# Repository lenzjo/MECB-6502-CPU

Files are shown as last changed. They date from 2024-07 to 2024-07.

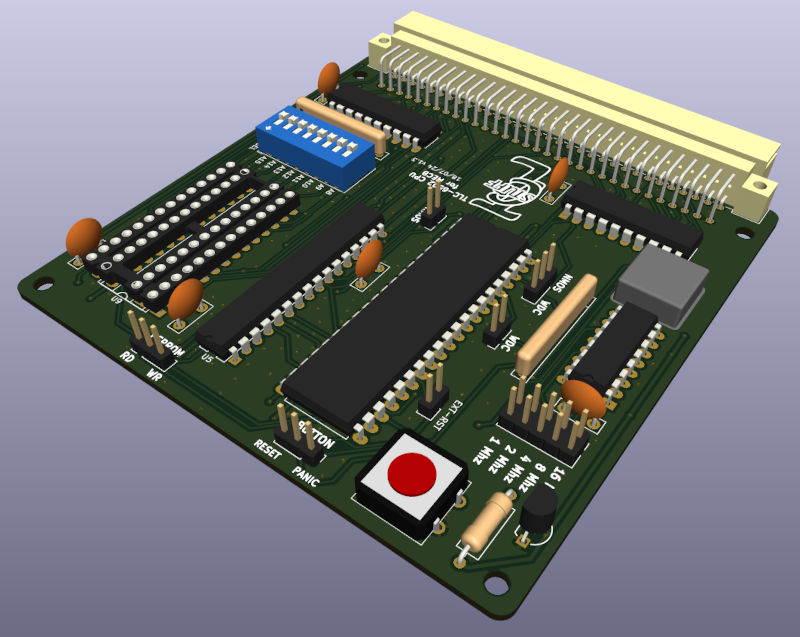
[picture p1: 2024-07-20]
TLC_6502_CPU.jpg

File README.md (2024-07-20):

# TLC-6502-CPU for MECB

This is the latest version of my 6502 pcb with several useful additions.

There are 3 sets of pin headers marked with **NMOS** and/or **WDC**. **WDC** refers to Western Digitals 65C02, If you're using that then jumper the pins marked **WDC**, otherwise jumper the **NMOS** marked pins.

This pcb uses a 16Mhz oscillator that is divided down to 1, 2, 4 and 8 Mhz. Jumper the relevant pair of pins for the clock speed you want.

The button's usage is jumper selectable. The **RESET** pin is connected to the reset line and the **PANIC** pin is connected to the **NMI** line. **PANIC** is only useful if your backplane has **Reset** button on it already, like mine. I am currently writing the needed firmware addition to TLCmon. If you are not using TLCmon then you will have to supply the necessary firmware.

The last set of pins (**EEPROM**) allow you to select if the eeprom is in either read or write mode. Under normal usage the **RD** pin should be jumpered.

You may have noticed the socket with double row pins. I have made a 28pin zif socket adapter that has pins spaced at 7.62mm. So on the pcb you use a cheap socket for the inner row of pins. When, if ever ;) , you finish developing your firmware you can solder in two rows of turned pins on the outer rows. I have included the gerbers for the adapter in the **gerbers** directory.

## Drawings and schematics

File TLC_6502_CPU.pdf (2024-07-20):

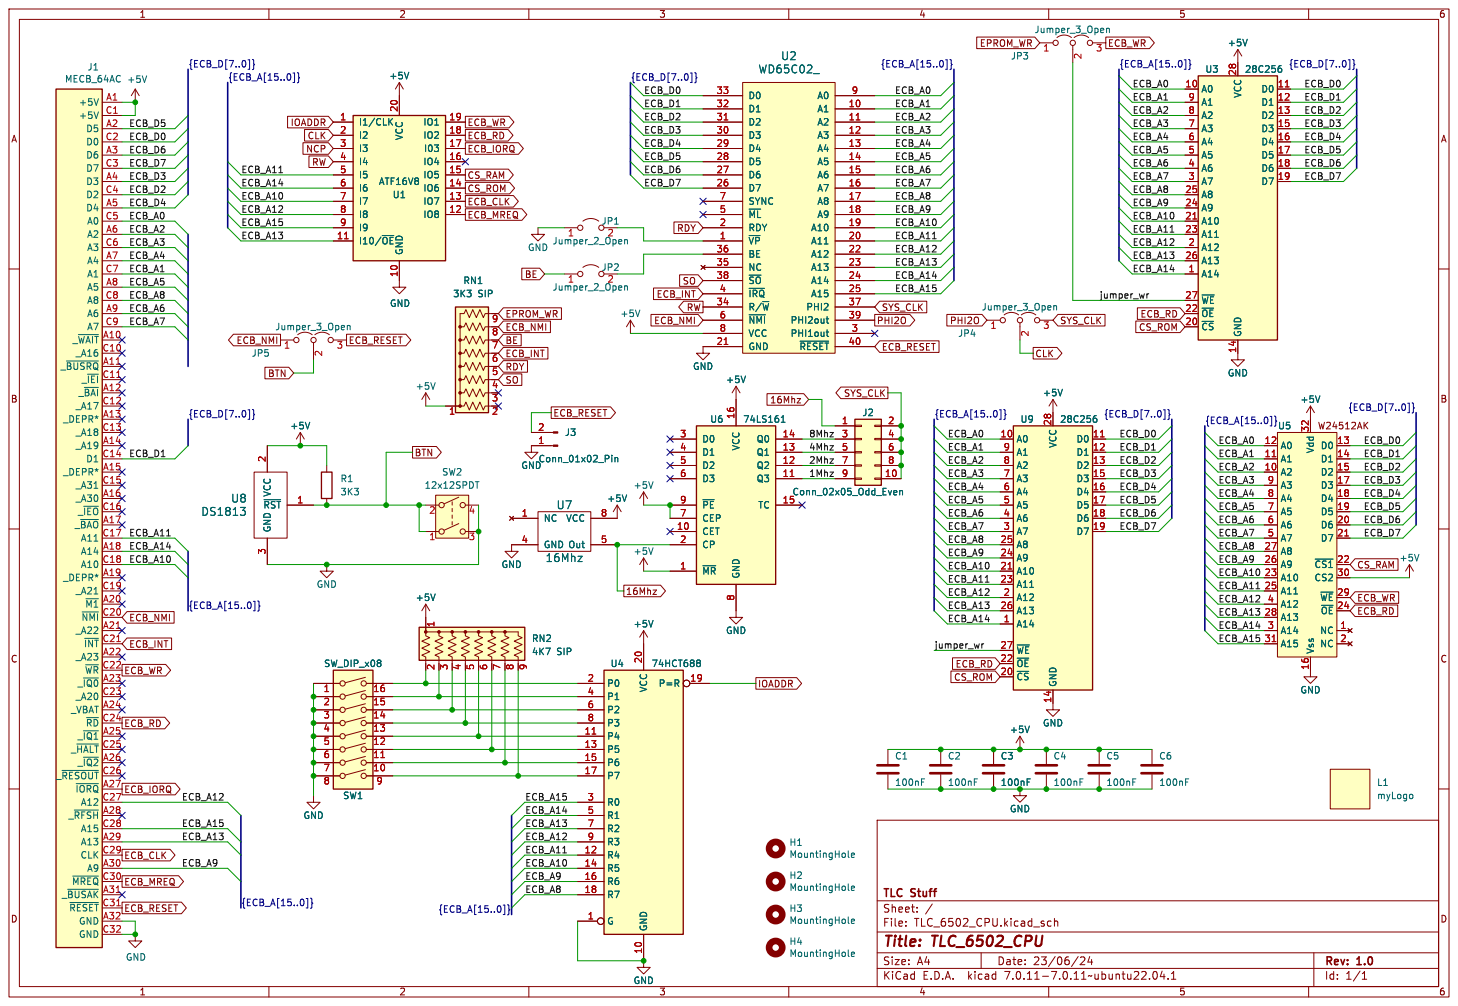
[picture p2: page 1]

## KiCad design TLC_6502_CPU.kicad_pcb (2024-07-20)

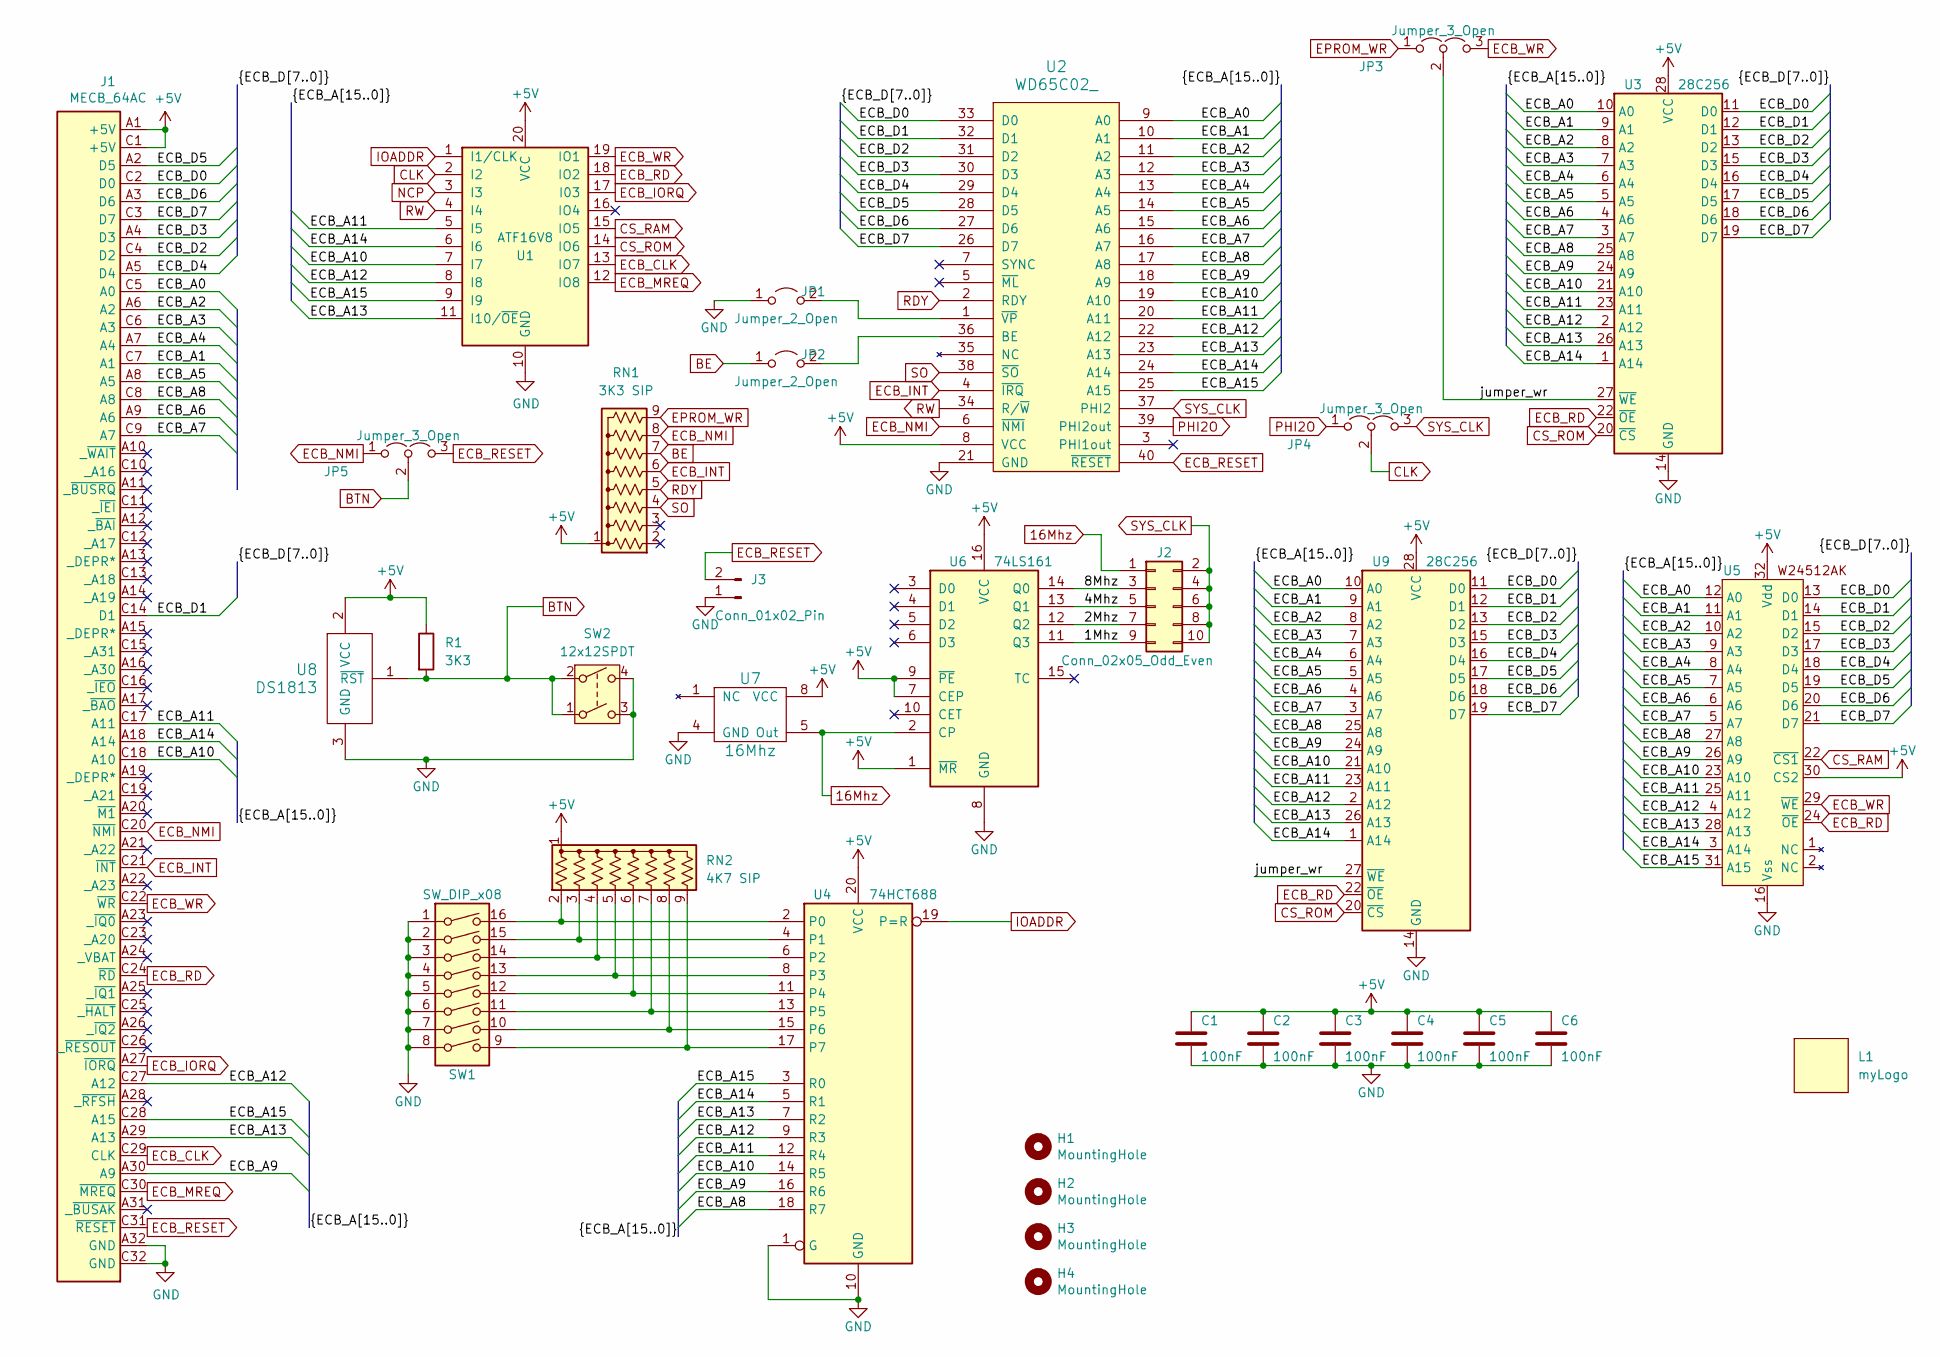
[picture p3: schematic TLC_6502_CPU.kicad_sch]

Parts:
C1, C2, C3, C4, C5, C6: 100nF; C_Disc_D7.5mm_W2.5mm_P5.00mm
H1, H2, H3, H4: MountingHole; MountingHole_3.2mm_M3
J1: MECB_64AC; DIN41612_C_2x32_C64AC_Male_Horizontal_THT
J2: Conn_02x05_Odd_Even; PinHeader_2x05_P2.54mm_Vertical
J3: Conn_01x02_Pin; PinHeader_1x02_P2.54mm_Vertical
JP1, JP2: Jumper_2_Open; PinHeader_1x02_P2.54mm_Vertical
JP3, JP4, JP5: Jumper_3_Open; PinHeader_1x03_P2.54mm_Vertical
L1: myLogo; LOGO_sm
R1: 3K3; R_Axial_DIN0309_L9.0mm_D3.2mm_P12.70mm_Horizontal
RN1: 3K3 SIP; R_Array_SIP9
RN2: 4K7 SIP; R_Array_SIP9
SW1: SW_DIP_x08; SW_DIP_SPSTx08_Slide_9.78x22.5mm_W7.62mm_P2.54mm
SW2: 12x12SPDT; 12x12-Tactile-Switch
U1: ATF16V8; DIP-20_W7.62mm_LongPads
U2: WD65C02_; DIP-40_W15.24mm_LongPads
U3: 28C256; DIP-28_W15.24mm_LongPads
U4: 74HCT688; DIP-20_W7.62mm_LongPads
U5: DIP-32_W7.62mm
U6: 74LS161; DIP-16_W7.62mm_LongPads
U7: 16Mhz; 4pinOsc
U8: DS1813; 21-0248A_MXM
U9: 28C256; DIP-28_W7.62mm_Socket_LongPads

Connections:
16Mhz: J2.1, U6.2 (CP), U7.5 (Out)
+5V: C1.1, C2.1, C3.1, C4.1, C5.1, C6.1, J1.A1 (+5V), J1.C1 (+5V), R1.1, RN1.1 (common), RN2.1 (common), U1.20 (VCC), U2.8 (VCC), U3.28 (VCC), U4.20 (VCC), U5.30 (CS2), U5.32 (Vdd), U6.1 (~MR), U6.7 (CEP), U6.9 (~PE), U6.16 (VCC), U7.8 (VCC), U8.2 (VCC), U9.28 (VCC)
/1Mhz: J2.9, U6.11 (Q3)
/2Mhz: J2.7, U6.12 (Q2)
/4Mhz: J2.5, U6.13 (Q1)
/8Mhz: J2.3, U6.14 (Q0)
/ECB_A0: J1.C5 (A0), U2.9 (A0), U3.10 (A0), U5.12 (A0), U9.10 (A0)
/ECB_A1: J1.C7 (A1), U2.10 (A1), U3.9 (A1), U5.11 (A1), U9.9 (A1)
/ECB_A2: J1.A6 (A2), U2.11 (A2), U3.8 (A2), U5.10 (A2), U9.8 (A2)
/ECB_A3: J1.C6 (A3), U2.12 (A3), U3.7 (A3), U5.9 (A3), U9.7 (A3)
/ECB_A4: J1.A7 (A4), U2.13 (A4), U3.6 (A4), U5.8 (A4), U9.6 (A4)
/ECB_A5: J1.A8 (A5), U2.14 (A5), U3.5 (A5), U5.7 (A5), U9.5 (A5)
/ECB_A6: J1.A9 (A6), U2.15 (A6), U3.4 (A6), U5.6 (A6), U9.4 (A6)
/ECB_A7: J1.C9 (A7), U2.16 (A7), U3.3 (A7), U5.5 (A7), U9.3 (A7)
/ECB_A8: J1.C8 (A8), U2.17 (A8), U3.25 (A8), U4.18 (R7), U5.27 (A8), U9.25 (A8)
/ECB_A9: J1.A30 (A9), U2.18 (A9), U3.24 (A9), U4.16 (R6), U5.26 (A9), U9.24 (A9)
/ECB_A10: J1.C18 (A10), U1.7 (I7), U2.19 (A10), U3.21 (A10), U4.14 (R5), U5.23 (A10), U9.21 (A10)
/ECB_A11: J1.C17 (A11), U1.5 (I5), U2.20 (A11), U3.23 (A11), U4.12 (R4), U5.25 (A11), U9.23 (A11)
/ECB_A12: J1.C27 (A12), U1.8 (I8), U2.22 (A12), U3.2 (A12), U4.9 (R3), U5.4 (A12), U9.2 (A12)
/ECB_A13: J1.A29 (A13), U1.11 (I10/~OE), U2.23 (A13), U3.26 (A13), U4.7 (R2), U5.28 (A13), U9.26 (A13)
/ECB_A14: J1.A18 (A14), U1.6 (I6), U2.24 (A14), U3.1 (A14), U4.5 (R1), U5.3 (A14), U9.1 (A14)
/ECB_A15: J1.C28 (A15), U1.9 (I9), U2.25 (A15), U4.3 (R0), U5.31 (A15)
/ECB_D0: J1.C2 (D0), U2.33 (D0), U3.11 (D0), U5.13 (D0), U9.11 (D0)
/ECB_D1: J1.C14 (D1), U2.32 (D1), U3.12 (D1), U5.14 (D1), U9.12 (D1)
/ECB_D2: J1.C4 (D2), U2.31 (D2), U3.13 (D2), U5.15 (D2), U9.13 (D2)
/ECB_D3: J1.A4 (D3), U2.30 (D3), U3.15 (D3), U5.17 (D3), U9.15 (D3)
/ECB_D4: J1.A5 (D4), U2.29 (D4), U3.16 (D4), U5.18 (D4), U9.16 (D4)
/ECB_D5: J1.A2 (D5), U2.28 (D5), U3.17 (D5), U5.19 (D5), U9.17 (D5)
/ECB_D6: J1.A3 (D6), U2.27 (D6), U3.18 (D6), U5.20 (D6), U9.18 (D6)
/ECB_D7: J1.C3 (D7), U2.26 (D7), U3.19 (D7), U5.21 (D7), U9.19 (D7)
/jumper_wr: JP3.2 (C), U3.27 (~WE), U9.27 (~WE)
BE: JP2.1 (A), RN1.7 (R6)
BTN: JP5.2 (C), R1.2, SW2.1, SW2.2, U8.1 (~RST)
CLK: JP4.2 (C), U1.2 (I2)
CS_RAM: U1.15 (IO5), U5.22 (~CS1)
CS_ROM: U1.14 (IO6), U3.20 (~CS), U9.20 (~CS)
ECB_CLK: J1.C29 (CLK), U1.13 (IO7)
ECB_INT: J1.C21 (~INT), RN1.6 (R5), U2.4 (~IRQ)
ECB_IORQ: J1.A27 (~IORQ), U1.17 (I03)
ECB_MREQ: J1.C30 (~MREQ), U1.12 (IO8)
ECB_NMI: J1.C20 (~NMI), JP5.1 (A), RN1.8 (R7), U2.6 (~NMI)
ECB_RD: J1.C24 (~RD), U1.18 (IO2), U3.22 (~OE), U5.24 (~OE), U9.22 (~OE)
ECB_RESET: J1.C31 (~RESET), J3.2, JP5.3 (B), U2.40 (~RESET)
ECB_WR: J1.C22 (~WR), JP3.3 (B), U1.19 (IO1), U5.29 (~WE)
EPROM_WR: JP3.1 (A), RN1.9 (R8)
GND: C1.2, C2.2, C3.2, C4.2, C5.2, C6.2, J1.A32 (GND), J1.C32 (GND), J3.1, JP1.1 (A), SW1.1, SW1.2, SW1.3, SW1.4, SW1.5, SW1.6, SW1.7, SW1.8, SW2.3, SW2.4, U1.10 (GND), U2.21 (GND), U3.14 (GND), U4.1 (G), U4.10 (GND), U5.16 (Vss), U6.8 (GND), U7.4 (GND), U8.3 (GND), U9.14 (GND)
IOADDR: U1.1 (I1/CLK), U4.19 (P=R)
NCP: U1.3 (I3)
unnamed: JP1.2 (B), U2.1 (~VP)
unnamed: JP2.2 (B), U2.36 (BE)
unnamed: RN2.2 (R1), SW1.16, U4.2 (P0)
unnamed: RN2.3 (R2), SW1.15, U4.4 (P1)
unnamed: RN2.4 (R3), SW1.14, U4.6 (P2)
unnamed: RN2.5 (R4), SW1.13, U4.8 (P3)
unnamed: RN2.6 (R5), SW1.12, U4.11 (P4)
unnamed: RN2.7 (R6), SW1.11, U4.13 (P5)
unnamed: RN2.8 (R7), SW1.10, U4.15 (P6)
unnamed: RN2.9 (R8), SW1.9, U4.17 (P7)
PHI2O: JP4.1 (A), U2.39 (PHI2out)
RDY: RN1.5 (R4), U2.2 (RDY)
RW: U1.4 (I4), U2.34 (R/~W)
SO: RN1.4 (R3), U2.38 (~SO)
SYS_CLK: J2.2, J2.4, J2.6, J2.8, J2.10, JP4.3 (B), U2.37 (PHI2)

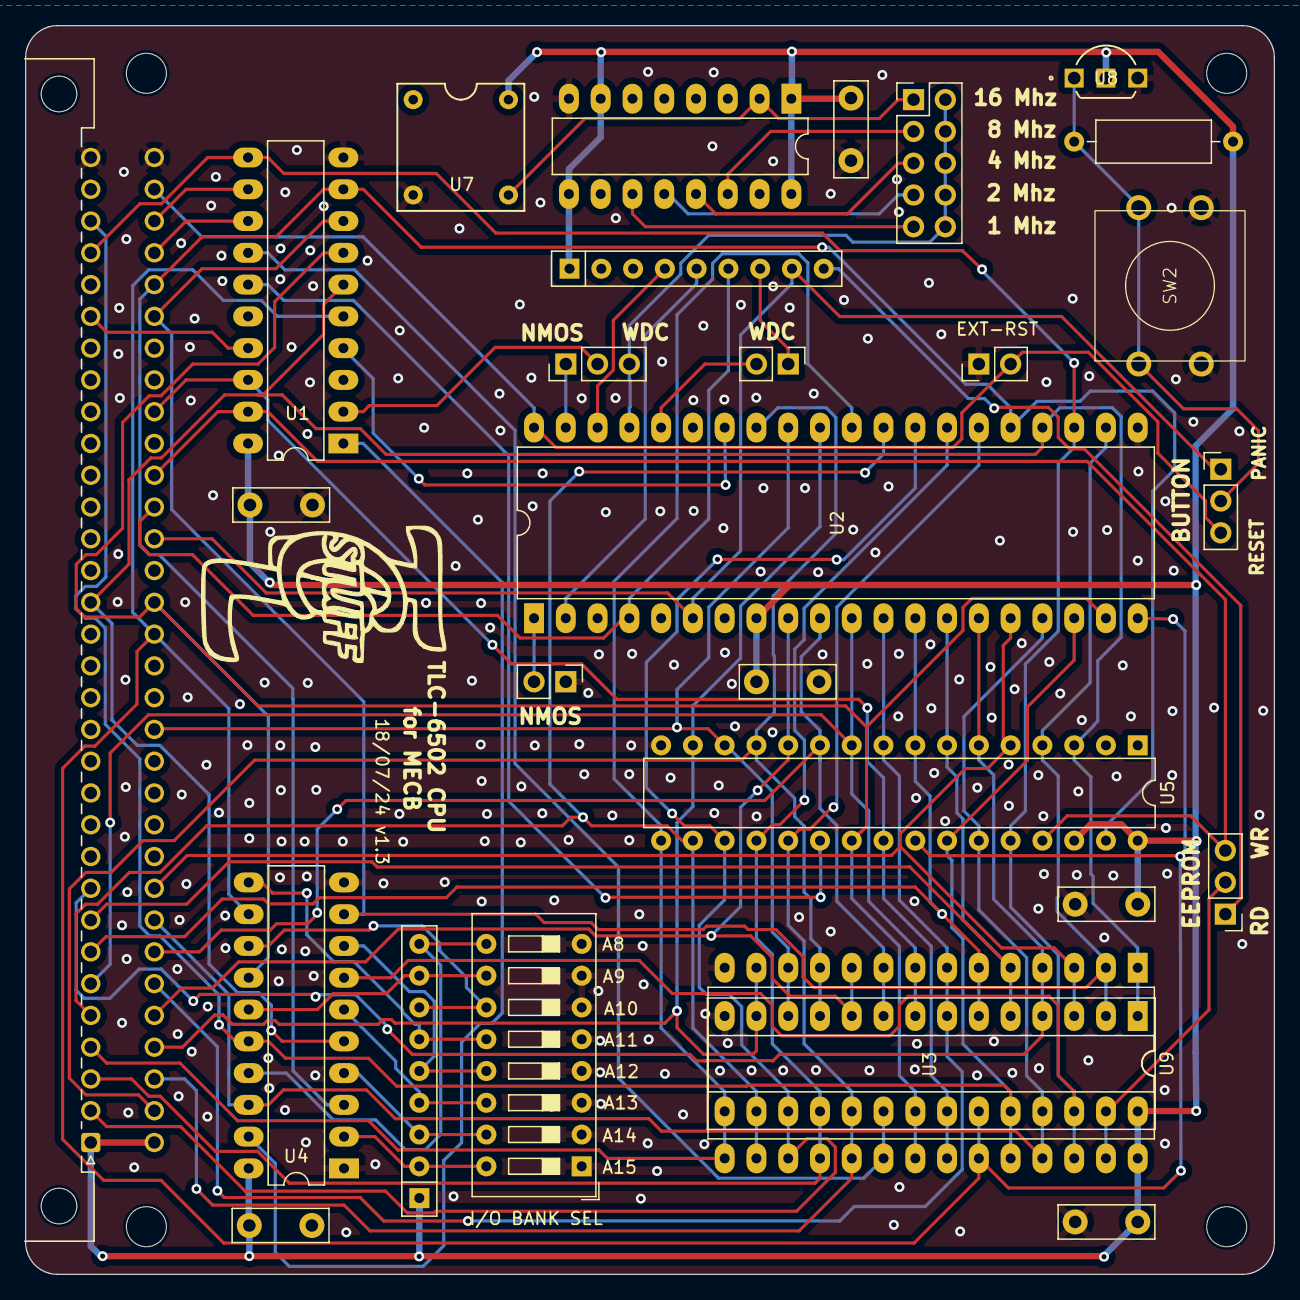
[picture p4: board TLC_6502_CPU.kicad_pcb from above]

Board: 2 copper layers, 99.8 x 99.8 mm, 33 parts (0 on the bottom side), 62 nets.
